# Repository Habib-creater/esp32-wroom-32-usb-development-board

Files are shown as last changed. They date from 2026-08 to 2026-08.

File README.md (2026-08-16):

# ESP32-WROOM-32 USB Development Board

A complete 2-layer ESP32-WROOM-32E development board designed in KiCad, integrating USB-to-UART programming, protected USB power input, 3.3 V regulation, BOOT/RESET control, GPIO expansion, and protected I²C interfaces.

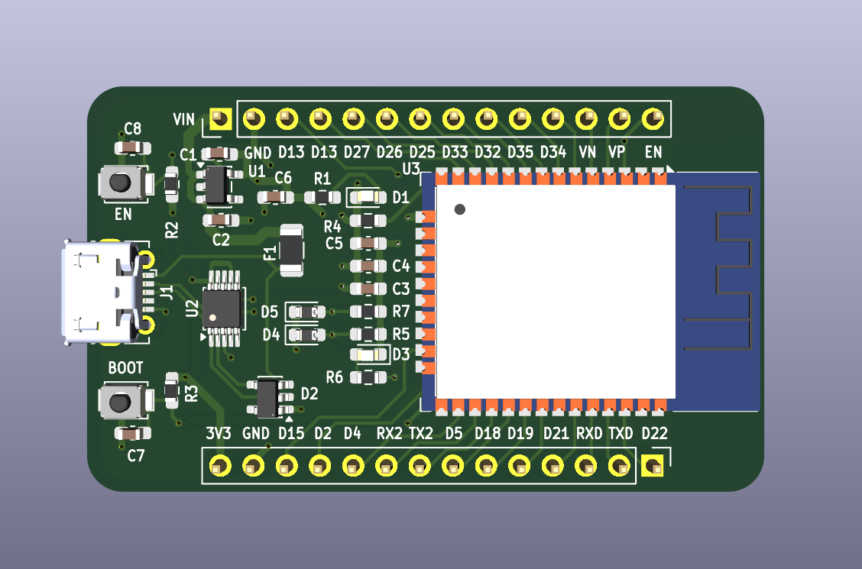
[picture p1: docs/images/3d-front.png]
ESP32-WROOM-32 USB Development Board


---

## Overview

This project presents the complete hardware design of a compact ESP32-WROOM-32E development board, including schematic capture, component selection, PCB layout, power distribution, interface protection, signal connectivity, design-rule verification, and manufacturing-data generation.

The design combines a Micro-USB interface, USB-to-UART bridge, regulated 3.3 V power architecture, ESP32 boot and reset circuitry, GPIO expansion headers, and protected I²C connectivity into a single 2-layer PCB.

The complete design package includes the KiCad schematic and PCB source files, bill of materials, manufacturing outputs, design documentation, PCB layout views, 3D board views, and verification records.

---

## Key Features

- ESP32-WROOM-32E based embedded hardware platform
- Micro-USB connectivity for power and USB communication
- CH340E USB-to-UART bridge powered from the +3.3 V rail
- AP2112K-3.3 low-dropout voltage regulator
- Protected USB power input with resettable fuse
- Dedicated USB ESD protection
- BOOT / GPIO0 programming control
- EN / RESET control
- GPIO expansion through dual 14-pin headers
- GPIO21 / GPIO22 dedicated to I²C SDA / SCL
- 4.7 kΩ I²C pull-up resistors
- AXGD10603NR low-capacitance ESD/TVS protection on I²C lines
- Local IC decoupling and bulk power filtering
- ESP32 antenna-region and RF keepout consideration
- 2-layer PCB layout
- Complete KiCad schematic and PCB source files
- Bill of Materials (BOM)
- Gerber and drill manufacturing outputs
- Electrical Rules Check (ERC) completed
- Design Rules Check (DRC) completed

---

## Project Specifications

| Parameter | Specification |
|---|---|
| MCU / Module | Espressif ESP32-WROOM-32E-H4 |
| USB Connector | Micro-USB, Molex 105017-0001 |
| USB-UART Bridge | CH340E |
| CH340E Supply | +3.3 V |
| Voltage Regulator | AP2112K-3.3 |
| USB ESD Protection | SP0503BAHT |
| I²C ESD Protection | 2 × AXGD10603NR |
| I²C SDA | GPIO21 |
| I²C SCL | GPIO22 |
| I²C Pull-ups | 4.7 kΩ to +3.3 V |
| Logic Voltage | 3.3 V |
| PCB Layers | 2 |
| PCB Thickness | 1.6 mm nominal |
| Board Dimensions | 51.75 mm × 31.00 mm |
| CAD Platform | KiCad 9.x |
| Design Verification | ERC + DRC completed |
| Hardware Status | PCB not yet fabricated |

---

## Functional Architecture

```mermaid
flowchart LR
    USB[Micro-USB] --> ESD[USB ESD Protection]
    ESD --> FUSE[500 mA Resettable Fuse]
    FUSE --> V5[+5 V Rail]

    V5 --> LDO[AP2112K-3.3]
    LDO --> V3[+3.3 V Rail]

    V3 --> ESP[ESP32-WROOM-32E]
    V3 --> UART[CH340E USB-UART]
    V3 --> I2C[I²C Pull-ups]

    UART <-->|UART0| ESP

    BOOT[BOOT / GPIO0] --> ESP
    RESET[EN / RESET] --> ESP

    I2C --> SDA[GPIO21 / SDA]
    I2C --> SCL[GPIO22 / SCL]

    SDA --> ESP
    SCL --> ESP

    ESP --> GPIO[GPIO Expansion Headers]
```

---

---

## Schematic

## Schematic

The complete electrical schematic is available as a PDF for detailed review.

[📄 View ESP32-WROOM-32 Schematic PDF](./archive/original/ESP32-WROOM-32-Schematic-original-export.pdf)

The PDF contains the complete electrical design, including:

- USB Micro-B input and power interface
- USB ESD protection
- Resettable USB input protection
- AP2112K-3.3 voltage regulation
- CH340E USB-to-UART interface
- ESP32-WROOM-32E module
- BOOT / GPIO0 control
- EN / RESET circuitry
- GPIO expansion headers
- I²C SDA / SCL interface
- I²C pull-up resistors
- I²C ESD/TVS protection
- Power decoupling and filtering
## PCB Layout

The PCB is a compact **51.75 mm × 31.00 mm, 2-layer design** with a nominal thickness of 1.6 mm.

### Layout View 1

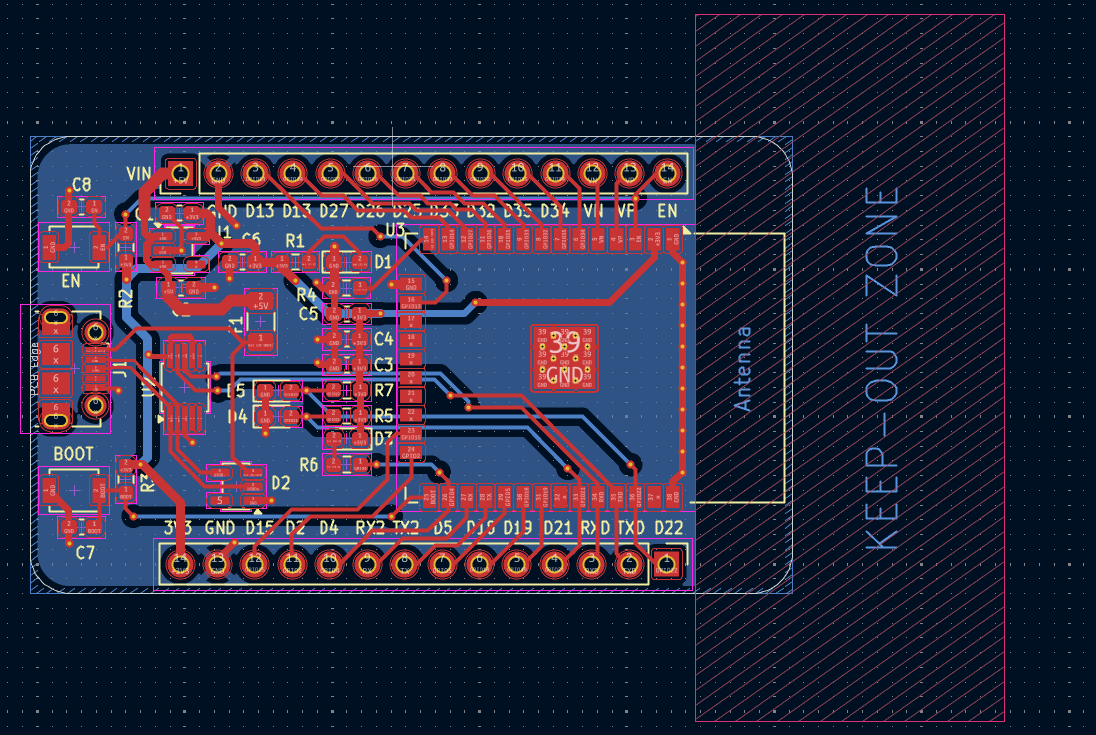
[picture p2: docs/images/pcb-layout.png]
ESP32-WROOM-32 PCB Layout


### Layout View 2

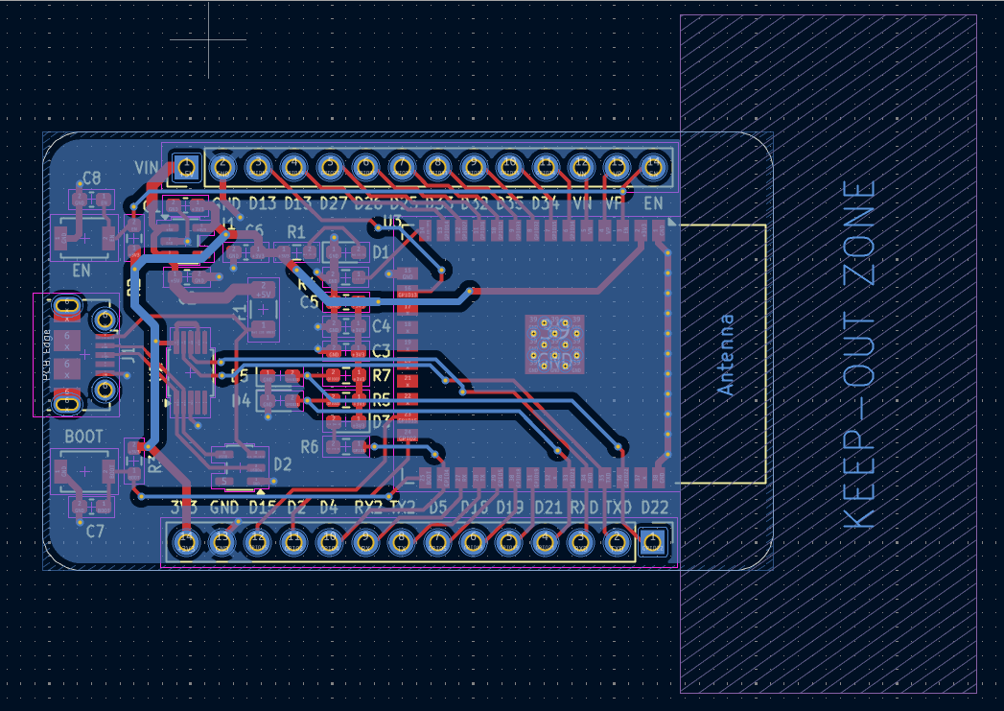
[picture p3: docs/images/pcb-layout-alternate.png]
ESP32-WROOM-32 Alternate PCB Layout


The PCB layout was developed with consideration for:

- ESP32 antenna region and RF keepout
- USB interface routing
- Power distribution
- Ground return paths
- Local IC decoupling
- Component placement
- Manufacturing clearances
- Board-edge constraints
- Signal routing

---

## PCB Routing

The completed PCB routing is shown below.

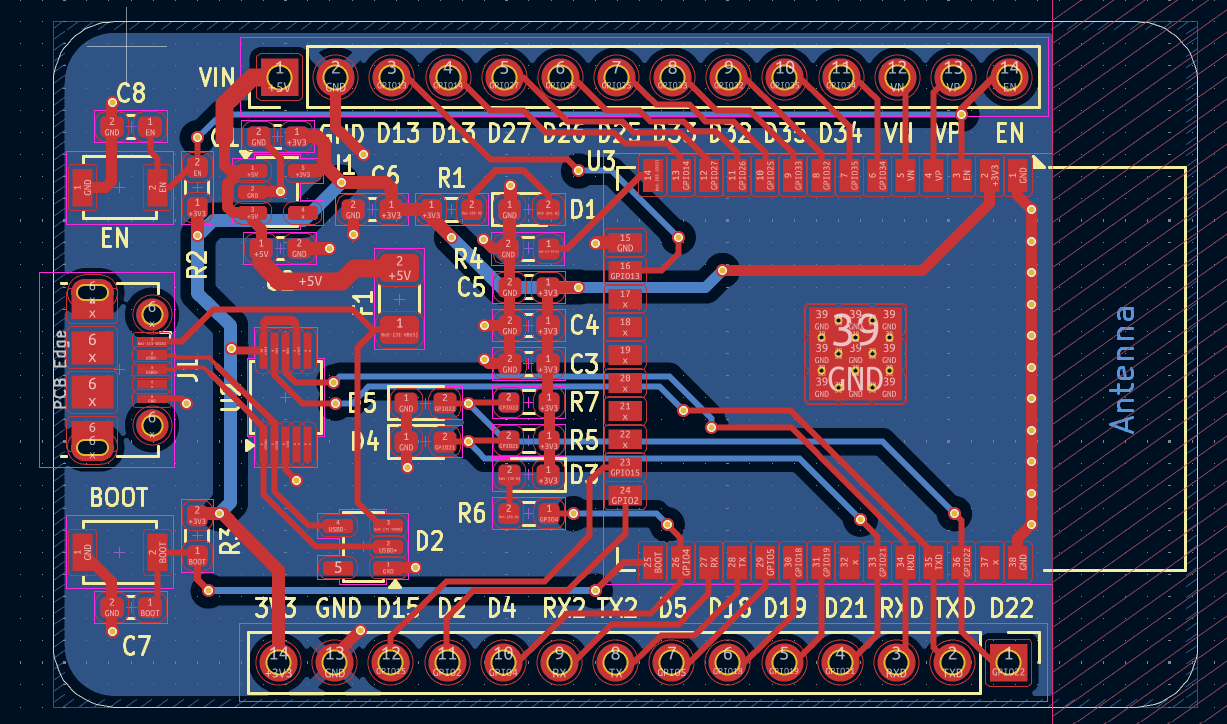
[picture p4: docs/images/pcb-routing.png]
ESP32-WROOM-32 PCB Routing


The routing includes:

- USB D+ / D−
- USB-to-UART connections
- ESP32 UART connections
- I²C signals
- Power distribution
- GPIO connections
- Ground connections

---

## 3D Board Views

### Front View

ESP32-WROOM-32 3D Front View

### Back View

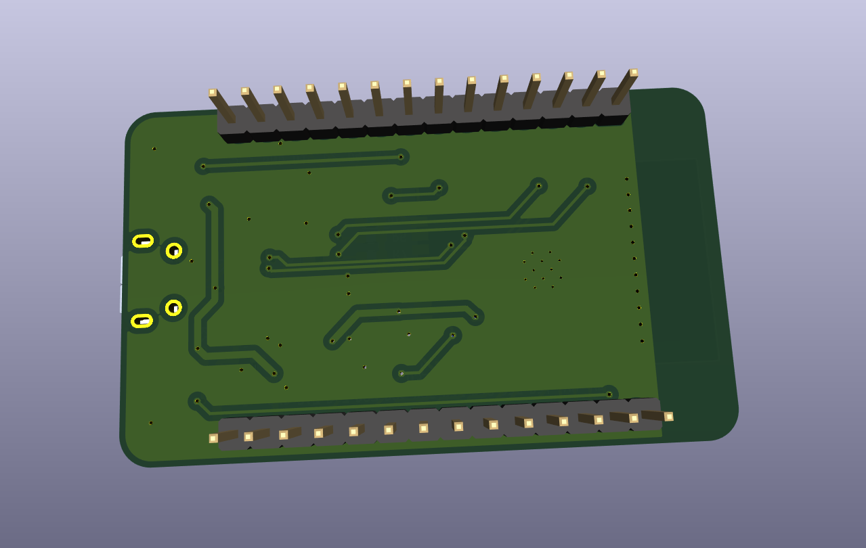
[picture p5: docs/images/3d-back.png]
ESP32-WROOM-32 3D Back View

---

## Design Verification

The schematic and PCB were reviewed using KiCad's electrical and physical design verification tools.

### Electrical Rules Check (ERC)

ERC was completed to review:

- Power connectivity
- Pin electrical types
- Net connectivity
- Unconnected pins
- Driver conflicts
- Interface connections
- Electrical rule violations

Relevant ERC issues were reviewed and resolved as part of the schematic verification process.

### Design Rules Check (DRC)

PCB DRC was completed to review:

- Track clearances
- Pad clearances
- Via clearances
- Board-edge clearances
- Copper constraints
- Solder-mask constraints
- Connectivity
- Manufacturing-rule constraints

The resulting PCB layout was reviewed for unresolved critical DRC violations.

### Verification Summary

| Verification Item | Status |
|---|---|
| Schematic ERC | ✅ Completed |
| PCB DRC | ✅ Completed |
| Net Connectivity | ✅ Reviewed |
| Component Footprints | ✅ Reviewed |
| Board Dimensions | ✅ Verified |
| Manufacturing Outputs | ✅ Generated |

---

## Manufacturing Data

The repository includes the generated manufacturing data associated with the PCB design.

The manufacturing package contains:

- Gerber copper layers
- Solder-mask layers
- Silkscreen layers
- Paste layers
- Board outline
- Drill files

**[View Manufacturing Documentation](docs/MANUFACTURING.md)**

---

## Bill of Materials

The project includes a component-level Bill of Materials for the board.

**[View Bill of Materials](hardware/bom/ESP32-WROOM-32_BOM.csv)**

The BOM contains component references, values, footprints, and available part/manufacturer information.

---

## Repository Structure

```text
ESP32-WROOM-32-USB-Development-Board/
│
├── README.md
├── LICENSE
├── CHANGELOG.md
├── .gitignore
├── .gitattributes
│
├── ESP32-WROOM-32-Schematic-original-export.pdf
│
├── hardware/
│   ├── kicad/
│   │   ├── ESP32-WROOM-32.kicad_pro
│   │   ├── ESP32-WROOM-32.kicad_sch
│   │   └── ESP32-WROOM-32.kicad_pcb
│   │
│   ├── bom/
│   │   └── ESP32-WROOM-32_BOM.csv
│   │
│   └── fabrication/
│       └── gerbers/
│
├── docs/
│   ├── SCHEMATIC.md
│   ├── ARCHITECTURE.md
│   ├── PINOUT.md
│   ├── MANUFACTURING.md
│   ├── VALIDATION.md
│   │
│   └── images/
│       ├── 3d-front.png
│       ├── 3d-back.png
│       ├── 3d_2.png
│       ├── pcb-layout.png
│       ├── pcb-layout-alternate.png
│       └── pcb-routing.png
│
├── project/
│   ├── design-notes.md
│   ├── repository-audit.md
│   └── SHA256SUMS.md
│
└── archive/
    └── original/
```

---

## Design Documentation

| Document | Description |
|---|---|
| [Architecture](docs/ARCHITECTURE.md) | Functional and power architecture |
| [Schematic Documentation](docs/SCHEMATIC.md) | Schematic organization and design blocks |
| [Pinout](docs/PINOUT.md) | GPIO and interface mapping |
| [Manufacturing](docs/MANUFACTURING.md) | Manufacturing-data inventory |
| [Validation](docs/VALIDATION.md) | Design verification information |
| [Design Notes](project/design-notes.md) | Engineering design notes |
| [Repository Audit](project/repository-audit.md) | Project package scope and status |

---

## Current Design Status

**Status: PCB design package completed**

The schematic, PCB layout, component selection, BOM, manufacturing outputs, and CAD-level design verification have been completed.

The PCB has **not yet been fabricated or hardware-validated**.

The repository therefore documents the CAD design and generated engineering files without claiming measured electrical, RF, thermal, assembly, or production results.

---

## Tools and Technologies

- KiCad 9.x
- Schematic Capture
- PCB Layout
- Electrical Rules Check (ERC)
- Design Rules Check (DRC)
- Gerber Generation
- Drill File Generation
- Bill of Materials Generation
- 3D PCB Visualization
- USB-UART Interface Design
- Power Supply Design
- ESD Protection
- I²C Interface Design

---

## License

This hardware design is released under the **CERN Open Hardware Licence Version 2 – Strongly Reciprocal (CERN-OHL-S-2.0)**.

See the [`LICENSE`](LICENSE) file for the complete licence terms.

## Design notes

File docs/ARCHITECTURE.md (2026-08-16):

# System Architecture

## Functional partition

```mermaid
flowchart TB
    USB[Micro-USB] --> ESD[USB ESD Protection]
    ESD --> FUSE[Resettable Fuse]
    FUSE --> V5[+5 V]
    V5 --> REG[AP2112K-3.3]
    REG --> V33[+3.3 V]

    V33 --> CH[CH340E USB-UART]
    V33 --> MCU[ESP32-WROOM-32E]
    CH <-->|UART0| MCU

    BOOT[BOOT / GPIO0] --> MCU
    EN[EN / RESET] --> MCU
    MCU --> SDA[GPIO21 / SDA]
    MCU --> SCL[GPIO22 / SCL]
    SDA --> IP[I²C Pull-ups + ESD]
    SCL --> IP
    MCU --> H[GPIO Headers]
```

## Power domains

| Rail | Source | Main loads |
|---|---|---|
| USB VBUS | Micro-USB | Input protection and 5 V domain |
| +5 V | VBUS through resettable fuse | AP2112K-3.3 input |
| +3.3 V | AP2112K-3.3 | ESP32-WROOM-32E, CH340E, I²C pull-ups, logic |
| GND | Board ground | Common return |

## Interfaces

- USB D+/D− → CH340E
- CH340E TXD/RXD ↔ ESP32 UART0
- GPIO21 → I²C SDA
- GPIO22 → I²C SCL
- GPIO0 → BOOT control
- EN → RESET control
- GPIO expansion → J2/J3

## Architecture summary

The design separates the USB input domain, regulated 3.3 V logic domain, USB-UART interface, ESP32 processing module, control circuitry, and external GPIO interfaces. The CH340E is powered from **+3.3 V**, while USB VBUS is used as the protected input source for the 5 V rail and the 3.3 V regulator.

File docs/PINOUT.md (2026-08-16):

# GPIO Header Pinout

The board exposes two 14-pin headers. Pin assignments below are taken from the PCB design nets.

## J2

| Pin | Net | Function / note |
|---:|---|---|
| 1 | GPIO22 | I²C SCL |
| 2 | TXD | ESP32 UART0 TX signal to USB-UART |
| 3 | RXD | ESP32 UART0 RX signal from USB-UART |
| 4 | GPIO21 | I²C SDA |
| 5 | GPIO19 | GPIO |
| 6 | GPIO18 | GPIO |
| 7 | GPIO5 | GPIO |
| 8 | TX | ESP32 TX breakout |
| 9 | RX | ESP32 RX breakout |
| 10 | GPIO4 | GPIO |
| 11 | GPIO2 | GPIO / boot-related usage should be considered in firmware |
| 12 | GPIO15 | GPIO / strapping considerations |
| 13 | GND | Ground |
| 14 | +3V3 | 3.3 V rail |

## J3

| Pin | Net | Function / note |
|---:|---|---|
| 1 | +5V | 5 V rail |
| 2 | GND | Ground |
| 3 | GPIO13 | GPIO |
| 4 | GPIO14 | GPIO |
| 5 | GPIO27 | GPIO |
| 6 | GPIO26 | GPIO |
| 7 | GPIO25 | GPIO |
| 8 | GPIO33 | GPIO / ADC capable |
| 9 | GPIO32 | GPIO / ADC capable |
| 10 | GPIO35 | Input-only GPIO / ADC capable |
| 11 | GPIO34 | Input-only GPIO / ADC capable |
| 12 | VN | ADC input (GPIO39) |
| 13 | VP | ADC input (GPIO36) |
| 14 | EN | Enable / reset |

## Dedicated control / interface signals

| Signal | ESP32 function |
|---|---|
| BOOT | GPIO0 bootstrapping control |
| EN | Chip enable / reset |
| SDA | GPIO21 |
| SCL | GPIO22 |
| RXD | UART0 RX |
| TXD | UART0 TX |

> GPIO34, GPIO35, GPIO36/VP, and GPIO39/VN are input-only on the classic ESP32. Firmware should account for their limitations.

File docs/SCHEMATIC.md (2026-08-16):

# Schematic

The canonical schematic source is:

`hardware/kicad/ESP32-WROOM-32.kicad_sch`

The schematic represents the electrical architecture of the academic ESP32 development-board project. An earlier exported PDF is retained under `archive/original/` for traceability.

## Functional sections

1. USB input and ESD protection
2. 5 V input protection and distribution
3. 3.3 V regulation
4. USB-to-UART bridge (**CH340E powered from +3.3 V**)
5. ESP32-WROOM-32E module
6. BOOT / GPIO0 control
7. EN / RESET control
8. I²C pull-ups and ESD protection
9. GPIO expansion headers

## Key electrical domains

- USB VBUS forms the protected input / +5 V domain.
- AP2112K-3.3 generates the +3.3 V logic rail.
- The ESP32-WROOM-32E and CH340E operate from the +3.3 V domain.
- GPIO21 and GPIO22 form the I²C SDA/SCL interface.

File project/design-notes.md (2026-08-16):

# Design Notes

## Scope

This academic project presents the design of a compact ESP32-WROOM-32 development board integrating USB programming, serial communication, regulated 3.3 V power, GPIO access, and protected I²C connectivity.

## Primary components

- ESP32-WROOM-32E-H4
- CH340E USB-UART bridge (**+3.3 V supply**)
- AP2112K-3.3 LDO
- SP0503BAHT USB ESD protection
- AXGD10603NR I²C ESD/TVS protection
- Molex 105017-0001 Micro-USB connector

## Board geometry

- 2-layer PCB
- 51.75 mm × 31.00 mm outline
- 1.6 mm nominal thickness

## Design considerations

- GPIO12 is an ESP32 strapping pin and its configuration is treated as a design consideration.
- D4/D5 use AXGD10603NR as low-capacitance ESD/TVS protection for the I²C lines.
- The ESP32 antenna region is treated as an RF-sensitive area in the PCB layout.
- The CH340E is connected to the regulated +3.3 V logic domain.

## Project status

The repository represents the academic CAD design and associated engineering files. The physical board has not been fabricated or hardware-tested.

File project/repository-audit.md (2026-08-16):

# Repository Audit

The repository is an academic design archive containing the supplied KiCad project, supporting documentation, and generated design-output files.

## Included

- KiCad schematic source
- KiCad PCB source
- KiCad project configuration
- BOM
- Schematic PDF archive
- 3D PCB renders
- PCB layout and routing captures
- Gerber data
- NC drill data
- Pick-and-place position files
- Engineering documentation

## Project status

The design has not been fabricated or hardware-validated. No electrical measurements, RF results, assembly results, or production-qualification claims are made in this repository.

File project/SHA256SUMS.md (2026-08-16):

# Source Manifest

SHA-256 hashes for the main project and documentation artifacts in this release.

- `.gitattributes` — `c22337d3911dba8e778a079e9cddec49ef5befcb478dcf8055bb8840696ca57d`
- `.gitignore` — `17954453cc4db56c79c13280bc190a9ac1008f1d8a72236e25ddc873584e07b8`
- `CHANGELOG.md` — `22866446523a615d24d3174107f0dadd12a3176eb197545dc980b21070b56c78`
- `LICENSE` — `36684fe875f8914fe9af1ecb36318b49027bc31b2f73c1116ad72687ec3db8d7`
- `README.md` — `beb3877d6491674556878d4a49b15a9401a58900e2a4d0d41e98bb7d6a626071`
- `archive/original/ESP32-WROOM-32-Schematic-original-export.pdf` — `f834f13157c191f0922dbc93e3181cfd9ba2172fc5fe5697c0e2f7f1350f2f84`
- `archive/original/ESP32-WROOM-32-local-settings.kicad_prl` — `830d12710ac7768775227a40c409e065490e81e9ceb201bbdb8c7f17bad0a84f`
- `archive/original/ESP32-WROOM-32-schematic-project.kicad_pro` — `937c43b4457b300da95eb26cc7f1625c0e7c22c4f7a7db92488d600aa29e3fde`
- `archive/original/Gerber-files-original.zip` — `971d10ba2f91369a2feaa5c93d3fb075969464fe3341e255b5e17154982284af`
- `docs/ARCHITECTURE.md` — `5820f05fafda45410c691d8041e55390d0cb9df73748db948d41f7fe9ef07288`
- `docs/MANUFACTURING.md` — `ac4cc14db2f703171f65bce028c2522d45288c2a3177593744864755c8f8e65f`
- `docs/PINOUT.md` — `be008da68e1cc7492db09eca8a0be07501b71c762ee0c0ccd1261d778df5291c`
- `docs/SCHEMATIC.md` — `17f57da81408eb7a65fc48d7f093084c104b3559b39af7f8bf97174f2f2cb312`
- `docs/VALIDATION.md` — `5fdd893c177ef68eac17f03ea38e6a29e78a4cea8ceacc02f6880ca14576b213`
- `docs/images/3d-back.png` — `5e814b01523aff0a52be717bfa461d5bb79e9cdb0a290bdbcdb6fd7e25b5c21e`
- `docs/images/3d-front.png` — `e0ea08ea8ce184a689c62998e04d3fca6c8c65ab4ad3bdb652bb09402b8d641f`
- `docs/images/pcb-layout-alternate.png` — `201e29295b1a2b29fa0f7324cfa98a368a77d64aff42121b8b9d4cb472542d7d`
- `docs/images/pcb-layout.png` — `deba211d32062db9e313662f9431243d4601b93ce364b8e546b59aa4b918ac0d`
- `docs/images/pcb-routing.png` — `095e13d832ba9381276cc568ace2f2ee95e327030a59e35dd2b486455b281c23`
- `hardware/bom/ESP32-WROOM-32_BOM.csv` — `3e506f2167dbbabaa2e0a677c23bc74c2b537125b384d1251249cb84f9510ff5`
- `hardware/bom/README.md` — `cdbc277ddf3359509c0f1d5ebd5f5e53a446531f17073da8886ea2032b95f840`
- `hardware/fabrication/gerbers/ESP32 WROOM 32-B_Cu.gbr` — `bb105b336eeeceabbf4e30fba1c2ee8893f892fc5d1b65b10f9d3de1880fe179`
- `hardware/fabrication/gerbers/ESP32 WROOM 32-B_Mask.gbr` — `30df2a11e81d982a76e65ee3b6e9a3eee4df2a7b38da3ea1d09f832d733f6a3e`
- `hardware/fabrication/gerbers/ESP32 WROOM 32-B_Paste.gbr` — `55da1254a07b242b6538c6cabdd60329de44e11d029f67c7b9a4892d009233f0`
- `hardware/fabrication/gerbers/ESP32 WROOM 32-B_Silkscreen.gbr` — `59ec2790c2c227014228258b6a325530fcafbf25f334637314e17b9465ec2f30`
- `hardware/fabrication/gerbers/ESP32 WROOM 32-Edge_Cuts.gbr` — `a8aa600330f78b38a431efeaac674c9fa2f15443f523edda743703774e2cd74d`
- `hardware/fabrication/gerbers/ESP32 WROOM 32-F_Cu.gbr` — `619a6800fd5cd26b39765ba5a6fac12b6de4f2ca43234f4961bf229982ef0385`
- `hardware/fabrication/gerbers/ESP32 WROOM 32-F_Mask.gbr` — `a3e69fd8440a097aff6d6e1b73943629a1a84e05e4332f0a236bb2f368c66ff4`
- `hardware/fabrication/gerbers/ESP32 WROOM 32-F_Paste.gbr` — `1d2f7c370d4ac93e1a7858c7d652f56634cea92a33551ed909b5c0a6b113503b`
- `hardware/fabrication/gerbers/ESP32 WROOM 32-F_Silkscreen.gbr` — `41a3e0a04a9aef3ebe38438caaf95dbd8c06ecd8a503a07d2a8b157d61672c01`
- `hardware/fabrication/gerbers/ESP32 WROOM 32-bottom.pos` — `0f3cfc3d6c4a4be94eff3f79dd6bc4cfa4ff51407ee297cf1e1aa81252fea7fe`
- `hardware/fabrication/gerbers/ESP32 WROOM 32-job.gbrjob` — `b2bc3ee434637d5ded23086e5da7e22bae44da07f1ea35026b9e81554b51ce31`
- `hardware/fabrication/gerbers/ESP32 WROOM 32-top.pos` — `898836c0b58bbab8ba6cb760b6f18ad4a62d5fb6f7b585308a112d585a7776d6`
- `hardware/fabrication/gerbers/ESP32 WROOM 32.drl` — `d2c2a3b99136d727d43dd84a5c6a3518bf268e3ad4e98e2a7ab3e49740923615`
- `hardware/kicad/ESP32-WROOM-32.kicad_pcb` — `8b643c558ab66fcaa2be5ab577ac67f9eccb0aee2bad67058061362d70b3fb06`
- `hardware/kicad/ESP32-WROOM-32.kicad_pro` — `6a67c966c0af01d3a8bfe6e43fbccba44d0ff207f43f9b5da8bab8c979c23e1c`
- `hardware/kicad/ESP32-WROOM-32.kicad_sch` — `ff7822761df1772f4dfdbdbbd600abaaeceb2bc334b5d65ac88e36c07196c115`
- `project/design-notes.md` — `be203f28deb2e3e81fc1b68c5292edb199d65fa93a65ec06e892f60cfa9684d2`
- `project/repository-audit.md` — `209b4afcac878fb8aa7fa591820ddbf67d7fbfd61426eff16a1dfc285f7583c6`

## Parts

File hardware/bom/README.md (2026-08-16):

# Bill of Materials

`ESP32-WROOM-32_BOM.csv` contains the component list associated with the academic PCB design.

The BOM records reference designators, quantities, component values, KiCad footprints, manufacturer information, and supplier information where available.

D4/D5 are documented as **ESD/TVS Protection** and use **Littelfuse AXGD10603NR**.

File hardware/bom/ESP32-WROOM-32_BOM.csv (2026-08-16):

Reference | Qty | Value | Footprint | Manufacturer | Manufactuerr Part No | Suppier Name | Supplier Link | Supplier Part No
C1,C2,C3 | 3 | 10u | Capacitor_SMD:C_0603_1608Metric_Pad1.08x0.95mm_HandSolder | YAGEO | CC0603MRX5R7BB106 | DigiKey | https://www.digikey.com/en/products/detail/yageo/CC0603MRX5R7BB106/5195229 | 311-1822-1-ND
C4,C5,C6,C7,C8 | 5 | 0.1u | Capacitor_SMD:C_0603_1608Metric_Pad1.08x0.95mm_HandSolder | YAGEO | CC0603KRX7R7BB104 | DigiKey | https://www.digikey.com/en/products/detail/yageo/CC0603KRX7R7BB104/302822 | 311-1088-1-ND
D1,D3 | 2 | Green | LED_SMD:LED_0603_1608Metric_Pad1.05x0.95mm_HandSolder | Vishay Semiconductor Opto Division | VLMG1300-GS08 | DigiKey | https://www.digikey.com/en/products/detail/vishay-semiconductor-opto-division/VLMG1300-GS08/2813350 | VLMG1300-GS08CT-ND
D2 | 1 | SP0503BAHT | Package_TO_SOT_SMD:SOT-23-5 | Littelfuse Inc. | SP0503BAHT | DigiKey | https://www.digikey.com/en/products/detail/littelfuse-inc/SP0503BAHT/485122 | SP0503BAHT-ND
D4,D5 | 2 | ESD/TVS Protection | Diode_SMD:D_0603_1608Metric_Pad1.05x0.95mm_HandSolder | Littelfuse Inc. | AXGD10603NR | DigiKey | https://www.digikey.com/en/products/detail/littelfuse-inc/AXGD10603NR/7219643 | F10020CT-ND
F1 | 1 | 500m | Fuse:Fuse_1206_3216Metric | Meritek | MPTS1206L050 | DigiKey | https://www.digikey.com/en/products/detail/meritek/MPTS1206L050/13879783 | 2997-MPTS1206L050TR-ND
J1 | 1 | USB_B_Micro | Connector_USB:USB_Micro-B_Molex-105017-0001 | Molex | 1050170001 | DigiKey | https://www.digikey.com/en/products/detail/molex/1050170001/2350832?s=N4IgTCBcDaIIwAYCsC4HYC0DtxAXQF8g | WM1399CT-ND
J2,J3 | 2 | Conn_01x14 | Connector_PinHeader_2.54mm:PinHeader_1x14_P2.54mm_Vertical | Same Sky (Formerly CUI Devices) | SSK01-MPH-254-A14 | DigiKey | https://www.digikey.com/en/products/detail/same-sky-formerly-cui-devices/SSK01-MPH-254-A14/28772127 | 2223-SSK01-MPH-254-A14-ND
R1 | 1 | 1k | Resistor_SMD:R_0603_1608Metric_Pad0.98x0.95mm_HandSolder | YAGEO | RC0603FR-071KL | DigiKey | https://www.digikey.com/en/products/detail/yageo/RC0603FR-071KL/726843 | 311-1.00KHRCT-ND
R2,R3,R4 | 3 | 10K | Resistor_SMD:R_0603_1608Metric_Pad0.98x0.95mm_HandSolder | YAGEO | RC0603FR-0710KL | DigiKey | https://www.digikey.com/en/products/detail/yageo/RC0603FR-0710KL/726880 | 311-10.0KHRCT-ND
R5,R7 | 2 | 4.7k | Resistor_SMD:R_0603_1608Metric_Pad0.98x0.95mm_HandSolder | YAGEO | RC0603FR-074K7L | DigiKey | https://www.digikey.com/en/products/detail/yageo/RC0603FR-074K7L/727212 | 311-4.70KHRCT-ND
R6 | 1 | 2.2k | Resistor_SMD:R_0603_1608Metric_Pad0.98x0.95mm_HandSolder | YAGEO | RC0603FR-072K2L | DigiKey | https://www.digikey.com/en/products/detail/yageo/RC0603FR-072K2L/727016 | 311-2.20KHRCT-ND
SW1,SW2 | 2 | SW_Push | Button_Switch_SMD:SW_SPST_B3U-1000P | Aratas (Formerly Omron Components) | B3U-1000P | DigiKey | https://www.digikey.com/en/products/detail/aratas-formerly-omron-components/B3U-1000P/1534338 | SW1020CT-ND
U1 | 1 | AP2112K-3.3 | Package_TO_SOT_SMD:SOT-23-5 | Diodes Incorporated | AP2112K-3.3TRG1 | DigiKey | https://www.digikey.com/en/products/detail/diodes-incorporated/AP2112K-3-3TRG1/4470746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 | AP2112K-3.3TRG1DICT-ND
U2 | 1 | CH340E | Package_SO:MSOP-10_3x3mm_P0.5mm | SparkFun Electronics | 16278 | DigiKey | https://www.digikey.com/en/products/detail/sparkfun-electronics/16278/17829769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 | 1568-16278-ND
U3 | 1 | ESP32-WROOM-32 | RF_Module:ESP32-WROOM-32 | Espressif Systems | ESP32-WROOM-32E-H4 | DigiKey | https://www.digikey.com/en/products/detail/espressif-systems/ESP32-WROOM-32E-H4/12696413 | 1965-ESP32-WROOM-32E-H4CT-ND

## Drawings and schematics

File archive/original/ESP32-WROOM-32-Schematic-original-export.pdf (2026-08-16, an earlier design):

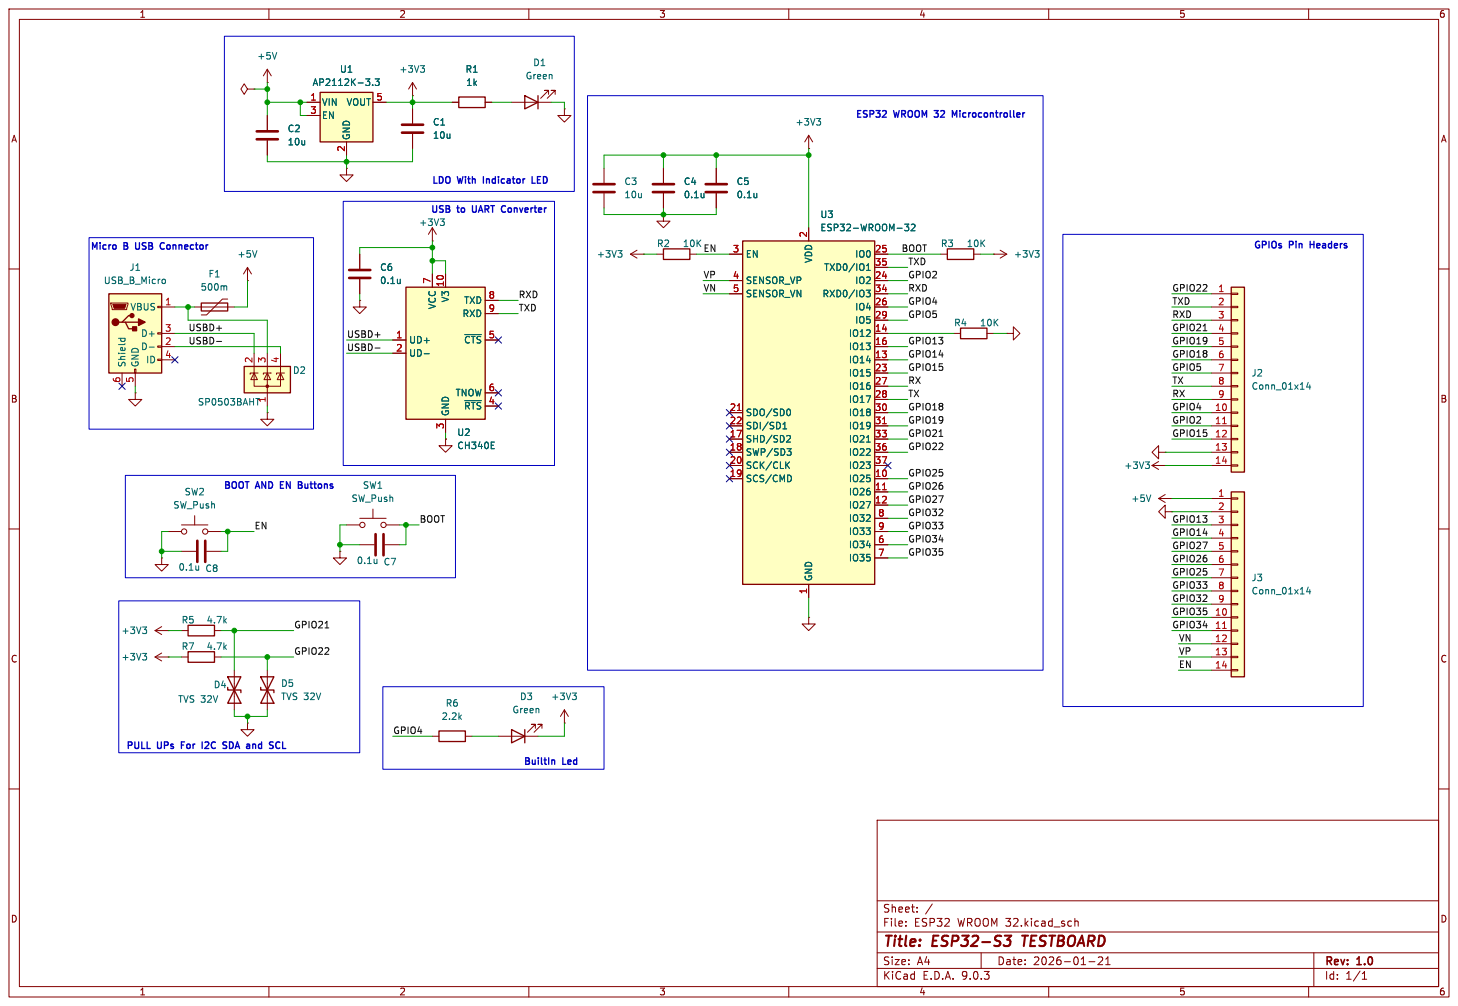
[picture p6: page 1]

3 TXD 8 RXD 9 ~{CTS}5 TNOW 6 ~{RTS}4 C6

3 TXD 8 RXD 9 ~{CTS}5 TNOW 6 ~{RTS}4 U2 CH340E

PULL UPs For I2C SDA and SCL

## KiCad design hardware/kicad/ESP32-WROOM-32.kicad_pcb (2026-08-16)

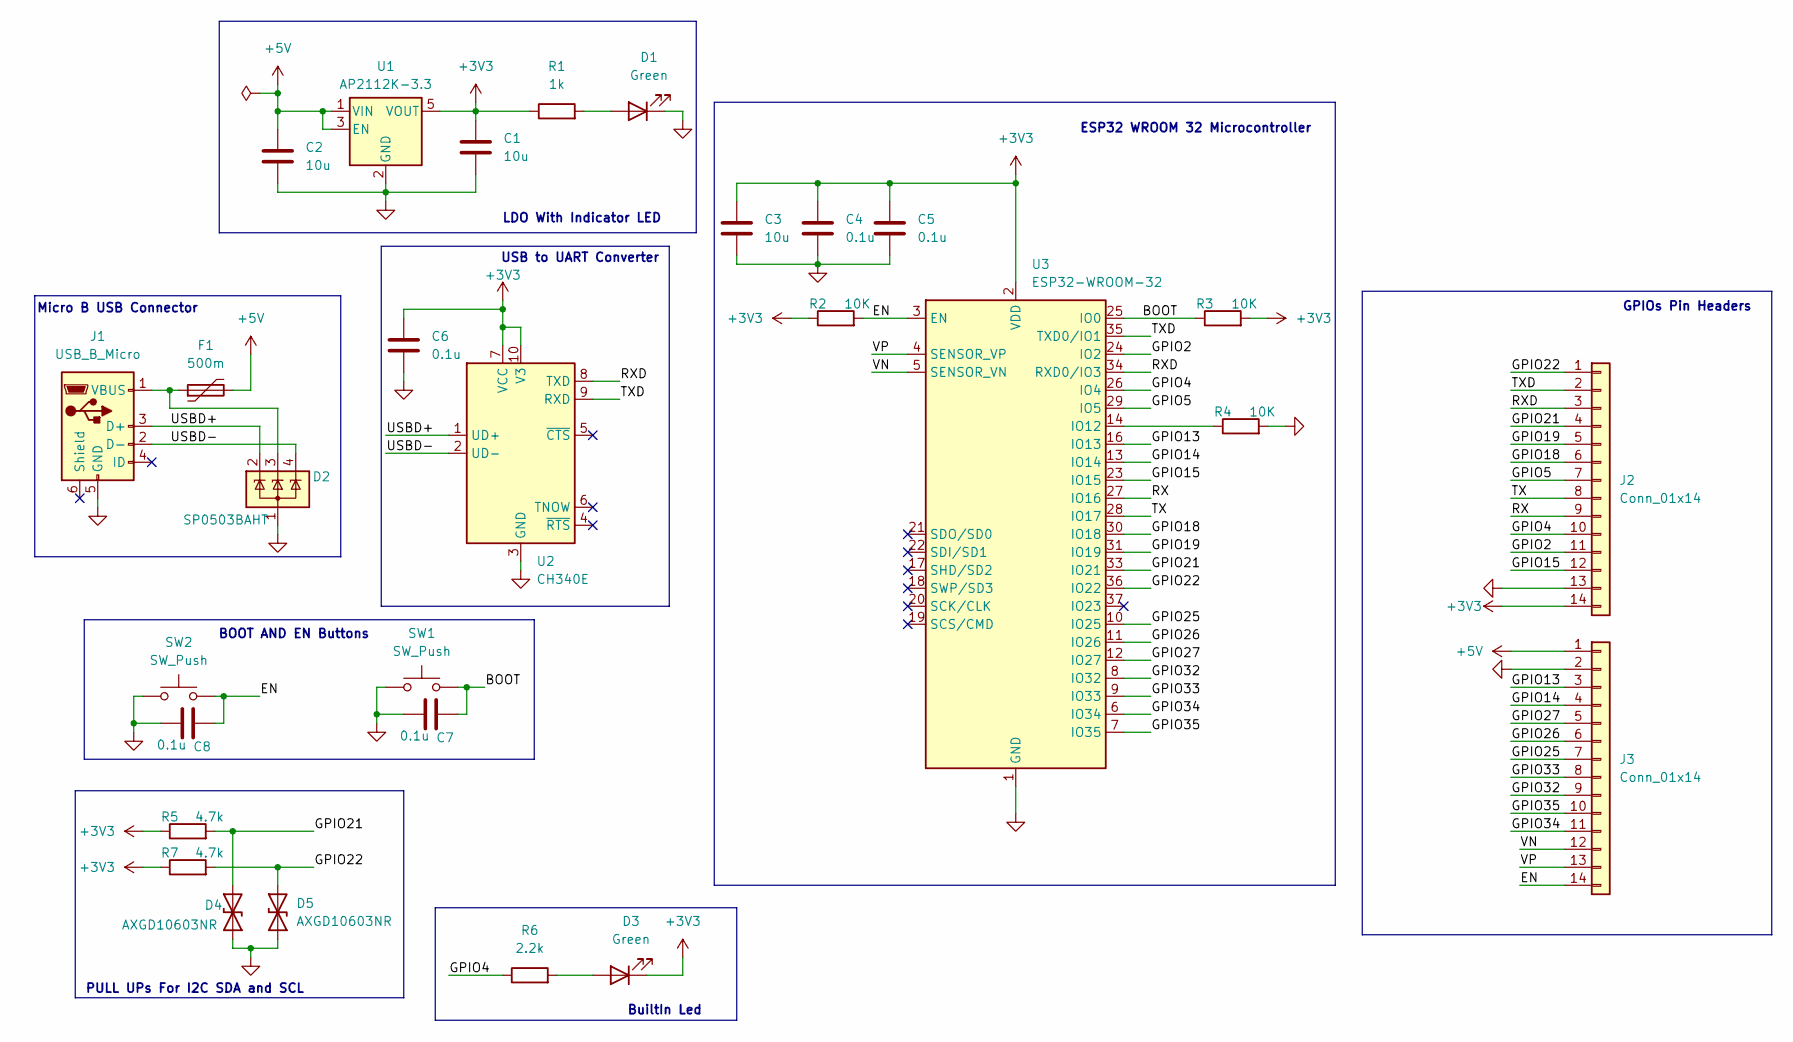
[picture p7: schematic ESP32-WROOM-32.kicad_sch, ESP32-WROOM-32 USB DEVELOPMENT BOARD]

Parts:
C1, C2, C3: 10u; C_0603_1608Metric_Pad1.08x0.95mm_HandSolder
C4, C5, C6, C7, C8: 0.1u; C_0603_1608Metric_Pad1.08x0.95mm_HandSolder
D1, D3: Green; LED_0603_1608Metric_Pad1.05x0.95mm_HandSolder
D2: SP0503BAHT; SOT-23-5
D4, D5: AXGD10603NR; D_0603_1608Metric_Pad1.05x0.95mm_HandSolder
F1: 500m; Fuse_1206_3216Metric
J1: USB_B_Micro; USB_Micro-B_Molex-105017-0001
J2, J3: Conn_01x14; PinHeader_1x14_P2.54mm_Vertical
R1: 1k; R_0603_1608Metric_Pad0.98x0.95mm_HandSolder
R2, R3, R4: 10K; R_0603_1608Metric_Pad0.98x0.95mm_HandSolder
R5, R7: 4.7k; R_0603_1608Metric_Pad0.98x0.95mm_HandSolder
R6: 2.2k; R_0603_1608Metric_Pad0.98x0.95mm_HandSolder
SW1, SW2: SW_Push; SW_SPST_B3U-1000P
U1: AP2112K-3.3; SOT-23-5
U2: CH340E; MSOP-10_3x3mm_P0.5mm
U3: ESP32-WROOM-32

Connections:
+3V3: C1.1, C3.1, C4.1, C5.1, C6.1, D3.1 (K), J2.14, R1.1, R2.1, R3.2, R5.1, R7.1, U1.5 (VOUT), U2.7 (VCC), U2.10 (V3), U3.2 (VDD)
+5V: C2.1, F1.2, J3.1, U1.1 (VIN), U1.3 (EN)
/BOOT: C7.1, R3.1, SW1.2, U3.25 (IO0)
/EN: C8.1, J3.14, R2.2, SW2.2, U3.3 (EN)
/GPIO2: J2.11, U3.24 (IO2)
/GPIO4: J2.10, R6.1, U3.26 (IO4)
/GPIO5: J2.7, U3.29 (IO5)
/GPIO13: J3.3, U3.16 (IO13)
/GPIO14: J3.4, U3.13 (IO14)
/GPIO15: J2.12, U3.23 (IO15)
/GPIO18: J2.6, U3.30 (IO18)
/GPIO19: J2.5, U3.31 (IO19)
/GPIO21: D4.2 (A2), J2.4, R5.2, U3.33 (IO21)
/GPIO22: D5.2 (A2), J2.1, R7.2, U3.36 (IO22)
/GPIO25: J3.7, U3.10 (IO25)
/GPIO26: J3.6, U3.11 (IO26)
/GPIO27: J3.5, U3.12 (IO27)
/GPIO32: J3.9, U3.8 (IO32)
/GPIO33: J3.8, U3.9 (IO33)
/GPIO34: J3.11, U3.6 (IO34)
/GPIO35: J3.10, U3.7 (IO35)
/RX: J2.9, U3.27 (IO16)
/RXD: J2.3, U2.8 (TXD), U3.34 (RXD0/IO3)
/TX: J2.8, U3.28 (IO17)
/TXD: J2.2, U2.9 (RXD), U3.35 (TXD0/IO1)
/USBD+: D2.2 (K), J1.3 (D+), U2.1 (UD+)
/USBD-: D2.4 (K), J1.2 (D-), U2.2 (UD-)
/VN: J3.12, U3.5 (SENSOR_VN)
/VP: J3.13, U3.4 (SENSOR_VP)
GND: C1.2, C2.2, C3.2, C4.2, C5.2, C6.2, C7.2, C8.2, D1.1 (K), D2.1 (A), D4.1 (A1), D5.1 (A1), J1.5 (GND), J2.13, J3.2, R4.2, SW1.1, SW2.1, U1.2 (GND), U2.3 (GND), U3.1 (GND), U3.15 (GND), U3.38 (GND), U3.39 (GND)
unnamed: D1.2 (A), R1.2
unnamed: D3.2 (A), R6.2
unnamed: D2.3 (K), F1.1, J1.1 (VBUS)
unnamed: R4.1, U3.14 (IO12)

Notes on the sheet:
PULL UPs For I2C SDA and SCL
Micro B USB Connector
BOOT AND EN Buttons
GPIOs Pin Headers
BuiltIn Led
LDO With Indicator LED
ESP32 WROOM 32 Microcontroller
USB to UART Converter

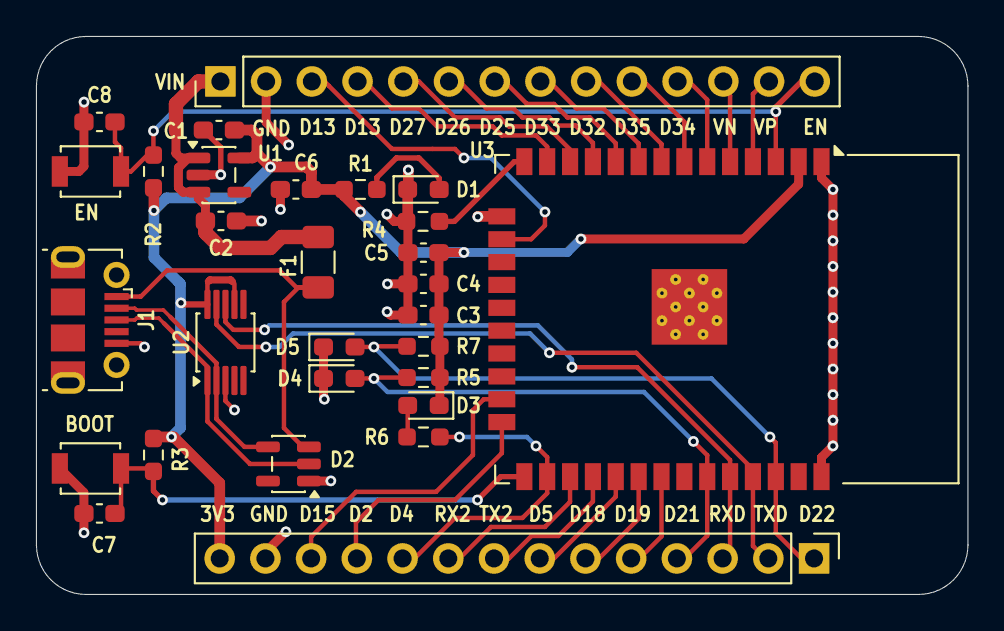
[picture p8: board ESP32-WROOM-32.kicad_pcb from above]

Board: 2 copper layers, 51.8 x 31.0 mm, 29 parts (0 on the bottom side), 34 nets.

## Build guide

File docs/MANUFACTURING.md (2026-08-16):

# Manufacturing Data

This directory records the manufacturing-related outputs generated from the PCB design for academic documentation and design traceability.

## Board definition

- **Board size:** 51.75 mm × 31.00 mm
- **PCB:** 2 copper layers
- **Nominal thickness:** 1.6 mm
- **Board outline:** Rounded rectangular profile
- **CAD:** KiCad 9.x

## Included data

The `hardware/fabrication/gerbers/` directory contains the generated design-output files, including:

- Front copper
- Back copper
- Front solder mask
- Back solder mask
- Front silkscreen
- Back silkscreen
- Front paste
- Back paste
- Edge cuts
- NC drill data
- Top and bottom component-position files
- Gerber job metadata

These files are retained as part of the academic design record. Their presence does not imply that the board has been fabricated, assembled, or production-qualified.

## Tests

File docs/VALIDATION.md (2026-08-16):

# Design Verification Status

This document records the current verification scope of the academic PCB design. It does not represent measured hardware validation.

## Current status

| Area | Status |
|---|---|
| Schematic design | Completed |
| PCB layout | Completed |
| BOM generation | Completed |
| Gerber / drill data generation | Completed |
| Hardware fabrication | **Not performed** |
| Hardware electrical measurements | **Not performed** |
| RF measurements | **Not performed** |
| Assembly validation | **Not performed** |
| Production qualification | **Not performed** |

## Design-review scope

The design documentation covers the following engineering considerations:

- ESP32-WROOM-32E power and control architecture
- USB-to-UART interface
- +5 V to +3.3 V power conversion
- CH340E operation from the +3.3 V logic domain
- BOOT/GPIO0 and EN/RESET circuitry
- GPIO and ADC exposure
- I²C pull-up network
- USB and I²C ESD protection
- ESP32 antenna-region layout considerations
- PCB geometry and generated manufacturing data

## Validation boundary

No measured results are presented because the physical PCB has not been fabricated. Any future electrical, communication, power-integrity, or RF results should be documented separately from this design-only release.

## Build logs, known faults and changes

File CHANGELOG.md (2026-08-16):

# Changelog

## 1.0.1 — Academic Documentation Revision

- Revised repository presentation as an academic PCB design project.
- Revised repository wording for academic documentation.
- Corrected board dimensions to **51.75 mm × 31.00 mm**.
- Corrected the architecture documentation to show **CH340E powered from +3.3 V**.
- Reframed manufacturing and validation documentation as design records.
- Removed the contribution guide from the academic project package.

## 1.0.0 — Design Package

- Added ESP32-WROOM-32 schematic.
- Added 2-layer PCB layout.
- Added USB-to-UART programming interface.
- Added AP2112K 3.3 V power stage.
- Added USB and I²C ESD protection.
- Added GPIO expansion headers.
- Added BOM with manufacturer part numbers.
- Added Gerber, drill, and position outputs.
- Added schematic, architecture, pinout, manufacturing, and validation documentation.
